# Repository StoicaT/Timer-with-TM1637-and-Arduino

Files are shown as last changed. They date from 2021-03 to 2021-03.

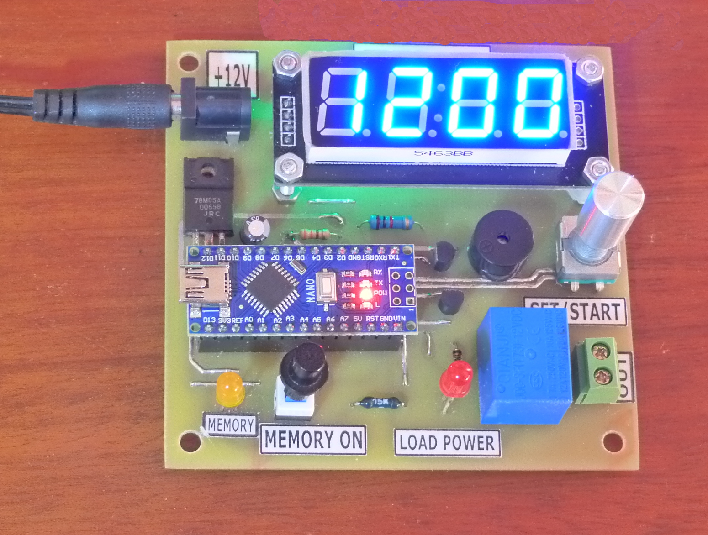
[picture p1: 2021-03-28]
Photo timer.JPG

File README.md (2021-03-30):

# Timer-with-TM1637-and-Arduino
Countdown timer with LED display drive by TM1637 and Arduino Nano.

This countdown timer allows timings in the 1-9999 seconds range. It is built around an Arduino Nano and timer programming is done with a rotary encoder. The display of the duration of the delay and the remaining time is made with LED display module with TM1637.This display is more visible than others I have previously presented, because the numbers are bigger and brighter.

Programming: Set number seconds (rotary encoder) -> push -> secondsX10 -> push -> 100Xseconds -> push -> 1000Xseconds. Now the time is set. The next push will trigger the delay.

During the time delay the load will be powered through the Rel relay. If the MEM button is pressed, no further programming is required, the previous value is retained. More to:
https://www.instructables.com/Timer-With-TM1637-and-Arduino/

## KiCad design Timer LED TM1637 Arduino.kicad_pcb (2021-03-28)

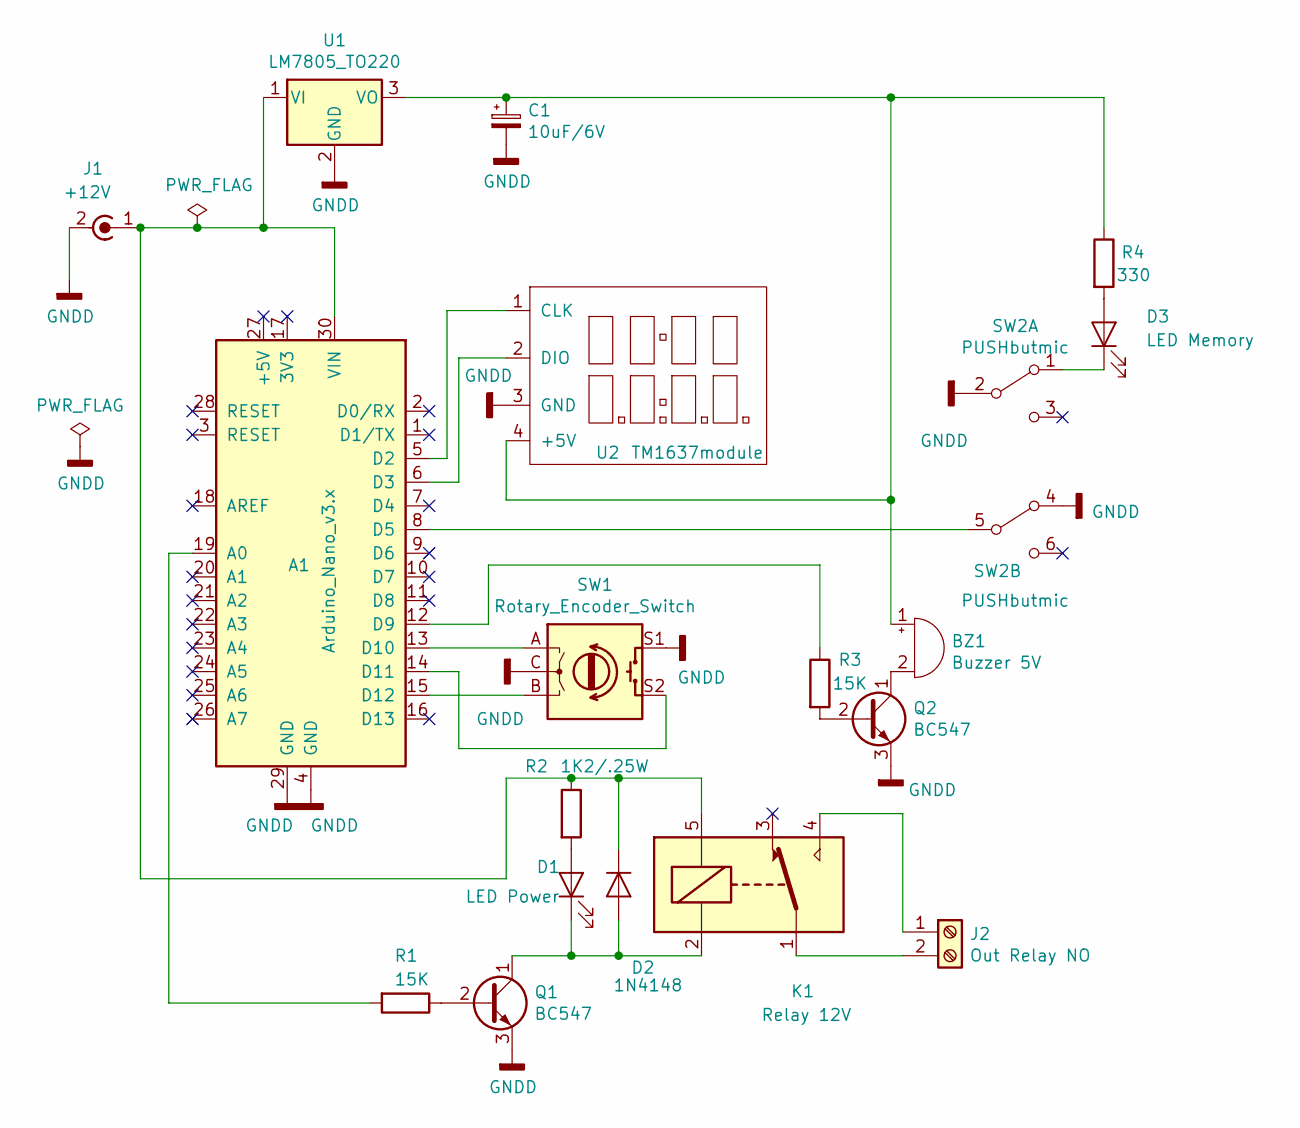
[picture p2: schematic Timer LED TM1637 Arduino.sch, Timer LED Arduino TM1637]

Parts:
A1: Arduino_Nano_v3.x; Arduino_Nano
BZ1: Buzzer 5V; Buzzer_12x9.5RM7.6
C1: 10uF/6V; CP_Radial_D5.0mm_P2.50mm
D1: LED Power; LED_D5.0mm
D2: 1N4148; D_DO-35_SOD27_P7.62mm_Horizontal
D3: LED Memory; LED_D5.0mm
J1: +12V; BarrelJack_Horizontal
J2: Out Relay NO; TerminalBlock_MetzConnect_Type094_RT03502HBLU_1x02_P5.00mm_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
K1: Relay 12V; Relay_SPDT_Omron-G5LE-1
Q1, Q2: BC547; TO-92_Inline
R1, R3: 15K; R_Axial_DIN0207_L6.3mm_D2.5mm_P10.16mm_Horizontal
R2: 1K2/.25W; R_Axial_DIN0309_L9.0mm_D3.2mm_P12.70mm_Horizontal
R4: 330; R_Axial_DIN0207_L6.3mm_D2.5mm_P10.16mm_Horizontal
SW1: Rotary_Encoder_Switch; RotaryEncoder_Alps_EC11E-Switch_Vertical_H20mm
SW2: PUSHbutmic; SWlinmic
U1: LM7805_TO220; TO-220-3_Horizontal_TabDown
U2: TM1637module; TM1637 module

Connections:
GNDD: A1.4 (GND), A1.29 (GND), C1.2, J1.2 (Ext), Q1.3 (E), Q2.3 (E), SW1.C, SW1.S1, SW2.2 (B), SW2.4 (A), U1.2 (GND), U2.3 (GND)
unnamed: A1.5 (D2), U2.1 (CLK)
unnamed: A1.6 (D3), U2.2 (DIO)
unnamed: A1.8 (D5), SW2.5 (B)
unnamed: A1.12 (D9), R3.1
unnamed: A1.13 (D10), SW1.A
unnamed: A1.14 (D11), SW1.S2
unnamed: A1.15 (D12), SW1.B
unnamed: A1.19 (A0), R1.2
unnamed: A1.30 (VIN), D2.1 (K), J1.1 (In), K1.5, R2.1, U1.1 (VI)
unnamed: BZ1.1 (-), C1.1, R4.1, U1.3 (VO), U2.4 (+5V)
unnamed: BZ1.2 (+), Q2.1 (C)
unnamed: D1.1 (K), D2.2 (A), K1.2, Q1.1 (C)
unnamed: D1.2 (A), R2.2
unnamed: D3.1 (K), SW2.1 (A)
unnamed: D3.2 (A), R4.2
unnamed: J2.1, K1.4
unnamed: J2.2, K1.1
unnamed: Q1.2 (B), R1.1
unnamed: Q2.2 (B), R3.2

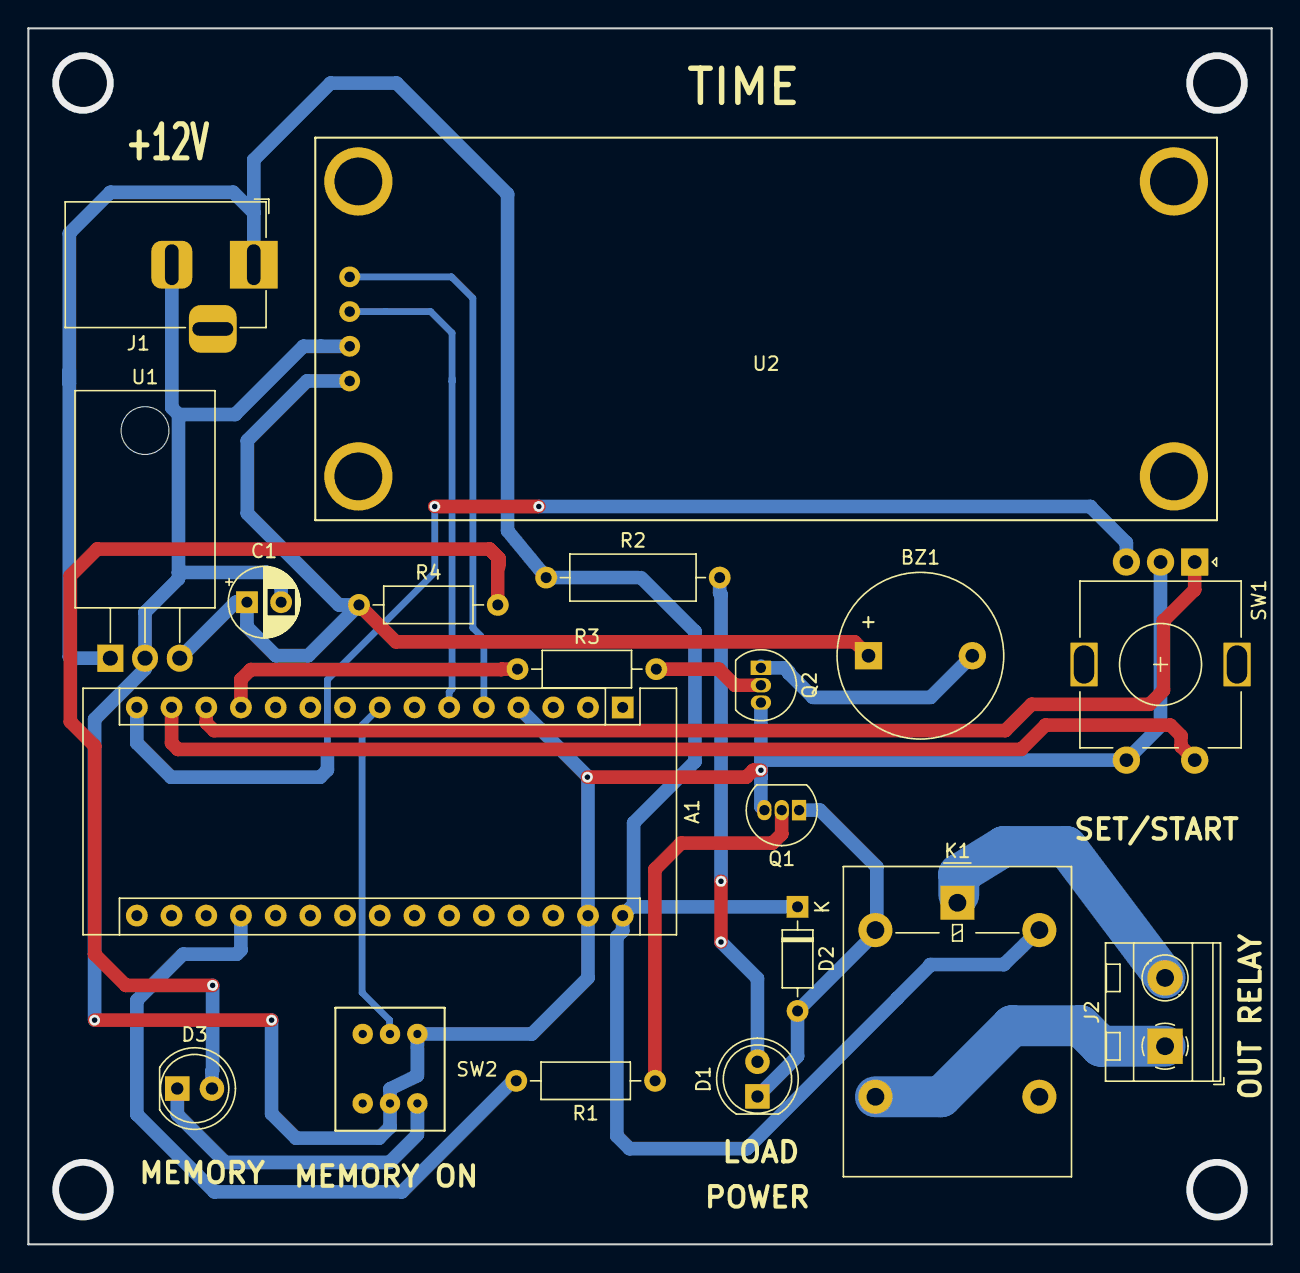
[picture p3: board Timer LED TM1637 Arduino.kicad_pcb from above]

Board: 2 copper layers, 91.0 x 89.0 mm, 19 parts (0 on the bottom side), 20 nets.

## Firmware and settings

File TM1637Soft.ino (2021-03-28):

//Designed by Stoica Tudor 02.2021  Rew 03.2021
//"Programable Timer" from n seconds to 0, n max=9999s.
// Possibility to memorize preset time.
// Rotary encoder

#include <Arduino.h>
#include <TM1637Display.h>

// Module connection pins (Digital Pins)
#define CLK 2
#define DIO 3


TM1637Display display(CLK, DIO);
byte u=0;// seconds s
byte z=0;// sX10
byte s=0;// sX100
byte m=0;// sX1000
int counter=0;
int n=0;
#define btMem 5 //Button "Memory" to ground
#define oRel A0 // OUT relay
#define oBuz 9 // OUT buzzer
#define pUsh 11 // OK rot. enc. to ground
#define rEnb 12 //Rot enc "B" to ground
#define rEna 10 //Rot enc "A" to ground
 
 
void setup()
{
pinMode(btMem, INPUT_PULLUP);//"Memory" button to GND 
pinMode(rEna, INPUT_PULLUP);//Rot enc left
pinMode(pUsh, INPUT_PULLUP);//OK button to GND
pinMode(rEnb, INPUT_PULLUP);//Rot enc right
pinMode(oRel,OUTPUT );//Out Relay
pinMode(oBuz,OUTPUT );//Out Buzzer
display.setBrightness(7);
 display.showNumberDec(0, true);
 delay(1000);
  display.clear();
  delay(1000);
   display.showNumberDec(0, true);
 digitalWrite((oBuz), HIGH);
 delay(1000);
digitalWrite((oBuz), LOW);

}

void loop()
{
  // set timer
 
  // set s. 
  do{
  u= roTen();
  //display.clear();
  display.showNumberDec(u); //Display the n value;
  delay(250);
  }while(digitalRead(pUsh)==HIGH);//"Push" button
  delay(250);
  counter=0;

// set sX10.
 display.showNumberDec(u,true,2,2);//Display 0u
do{
  z= roTen();
  n=z*10+u;
  //display.clear();
  display.showNumberDec(n , true,2,2); //Display the n value;
  delay(250);
  }while(digitalRead(pUsh)==HIGH);//"Push" button
  delay(250);
  counter=0;

  // set sX100. 
do{
  s= roTen();
  n=s*100+z*10+u;
  //display.clear();
  display.showNumberDec(n , true, 3, 1); //Display the n value;
  delay(250);
  }while(digitalRead(pUsh)==HIGH);//"Push" button
  delay(250);
  counter=0;

   // set sX1000. 
do{
  m= roTen();
  n=m*1000+s*100+z*10+u;
  //display.clear();
  display.showNumberDec(n , true, 4,0); //Display the n value;
  delay(250);
  }while(digitalRead(pUsh)==HIGH);//"Push" button
  delay(250);
  counter=0;
  //Out of set routine
 
    n=m*1000+s*100+z*10+u;//compute "n"
    if(n!=0){
    
  do{//Memory  
    n=m*1000+s*100+z*10+u;//compute "n"
    
     //display set "n"
     
   display.showNumberDec(n);
   
while(0==digitalRead(pUsh));//"Push" button to start
while(1==digitalRead(pUsh));
delay(50);


  digitalWrite(oRel,HIGH);//Start Rel
  
  do{// decrease time
  //display current "n"
   display.showNumberDec(n);
  
  while(millis() % 1000 != 0);//time base, 1s.
  
  n=n-1;
  }while(n!=0);
  
   
  display.showNumberDec(n);//display n=0
  
  digitalWrite(oRel,LOW);//Stop Rel
  
digitalWrite(oBuz,HIGH);// start beep to end
delay(1000);
digitalWrite(oBuz,LOW);   //  stop beep to end

  }while(digitalRead(btMem)==LOW);//"Memory" button
  u=0;
  z=0;
  s=0;
  m=0;
}
}

byte roTen(){ //  Rotary encoder routine
 while(digitalRead(pUsh) &digitalRead(rEnb) & digitalRead(rEna)==1);
  if(digitalRead(pUsh)==0){
  return counter;
  }
   switch(digitalRead(rEna)) {
    case HIGH:
    while(digitalRead(rEna)==0);
    while(digitalRead(rEnb)==0);
    counter ++;
    counter=counter%10;
    break;
    case LOW:
   while(digitalRead(rEnb)==0);
   while(digitalRead(rEna)==0);
   counter --;
    if(counter==-1){
    counter=9;//left begin with 9
    } 
    counter=abs(counter)%10;
  break; 
  }
  return counter;
   }                      
 
